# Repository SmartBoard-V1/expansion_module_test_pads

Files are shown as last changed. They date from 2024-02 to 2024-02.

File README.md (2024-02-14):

# # Expansion Module: Test Pads with LEDs








## Overview
This repository is dedicated to the design and implementation of the Test Pads with LEDs Expansion Module, an advanced diagnostic tool crafted to enhance the testing and debugging processes of electronic circuits. With its integration of 8 test pads linked to LED indicators and an additional LED for power status verification, this module stands as a critical asset for developers. It excels in facilitating the examination of signal integrity within FPGA configurations on SmartBoard connectors, especially useful in identifying potential line damage caused by the integration of improperly designed expansion modules. Moreover, its utility extends to the observation and testing of signal outputs from the FPGA to external analysis equipment, such as oscilloscopes or logic analyzers, making it invaluable for real-time signal monitoring during module communication interface testing.

## Key Features
- **LED Indicators**: Features 8 LEDs associated with test pads for immediate visual feedback on signal status, plus one additional LED to confirm power supply integrity.
- **Dual Functionality**:
  - Enables the testing of signal paths on FPGA pads within SmartBoard connectors, aiding in the quick identification of any damaged lines due to faulty expansion module connections.
  - Facilitates the external monitoring and testing of FPGA output signals, allowing for the rerouting of internal signals to this module for analysis with oscilloscopes or logic analyzers.
- **Versatile Testing Capability**: Specially designed for a broad spectrum of electronic testing and debugging scenarios, enhancing both prototype development and troubleshooting efforts.

## Design Documentation

### Schematic Diagram
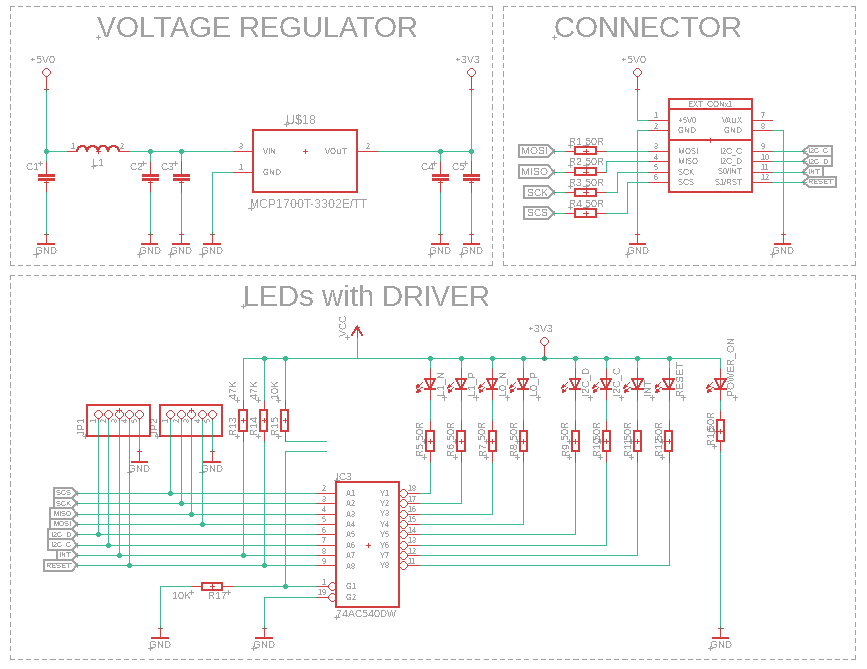
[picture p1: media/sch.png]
Schematic Diagram

*This schematic diagram outlines the layout and connections of the test pads and LEDs, providing a clear guide for replication or modification.*

### Board Design - 2D
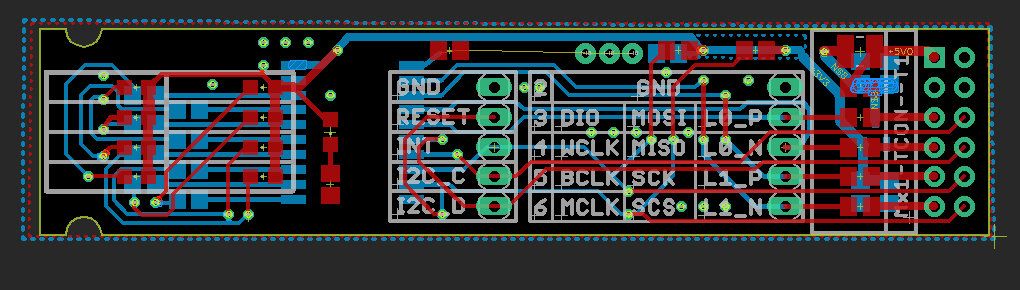
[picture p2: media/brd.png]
Board Design - 2D

*The 2D board design illustrates the placement of LEDs and test pads on the PCB, ensuring optimal accessibility for testing purposes.*

## Contributions and Feedback
We welcome contributions and suggestions for improvements to this module. If you have developed enhancements or have ideas for additional features, please fork the repository, implement your changes, and submit a pull request. For any questions or issues, open an issue in the GitHub repository.

## License
This expansion module is licensed under the MIT License, providing flexibility for both private and commercial use under the following terms:

- **Permission to Use**: Freedom to use, modify, and distribute the module design.
- **Attribution**: While not mandatory, crediting the original author, Adam Łuczak, is appreciated.
- **No Warranty**: Provided "as is", without any warranty; use at your own risk.
- **Liability**: The author bears no liability for any damages or losses.

For full license terms, please refer to the MIT License documentation in this repository.

## Contact
For inquiries or suggestions regarding this project, please contact Adam Łuczak at adam.luczak@outlook.com.

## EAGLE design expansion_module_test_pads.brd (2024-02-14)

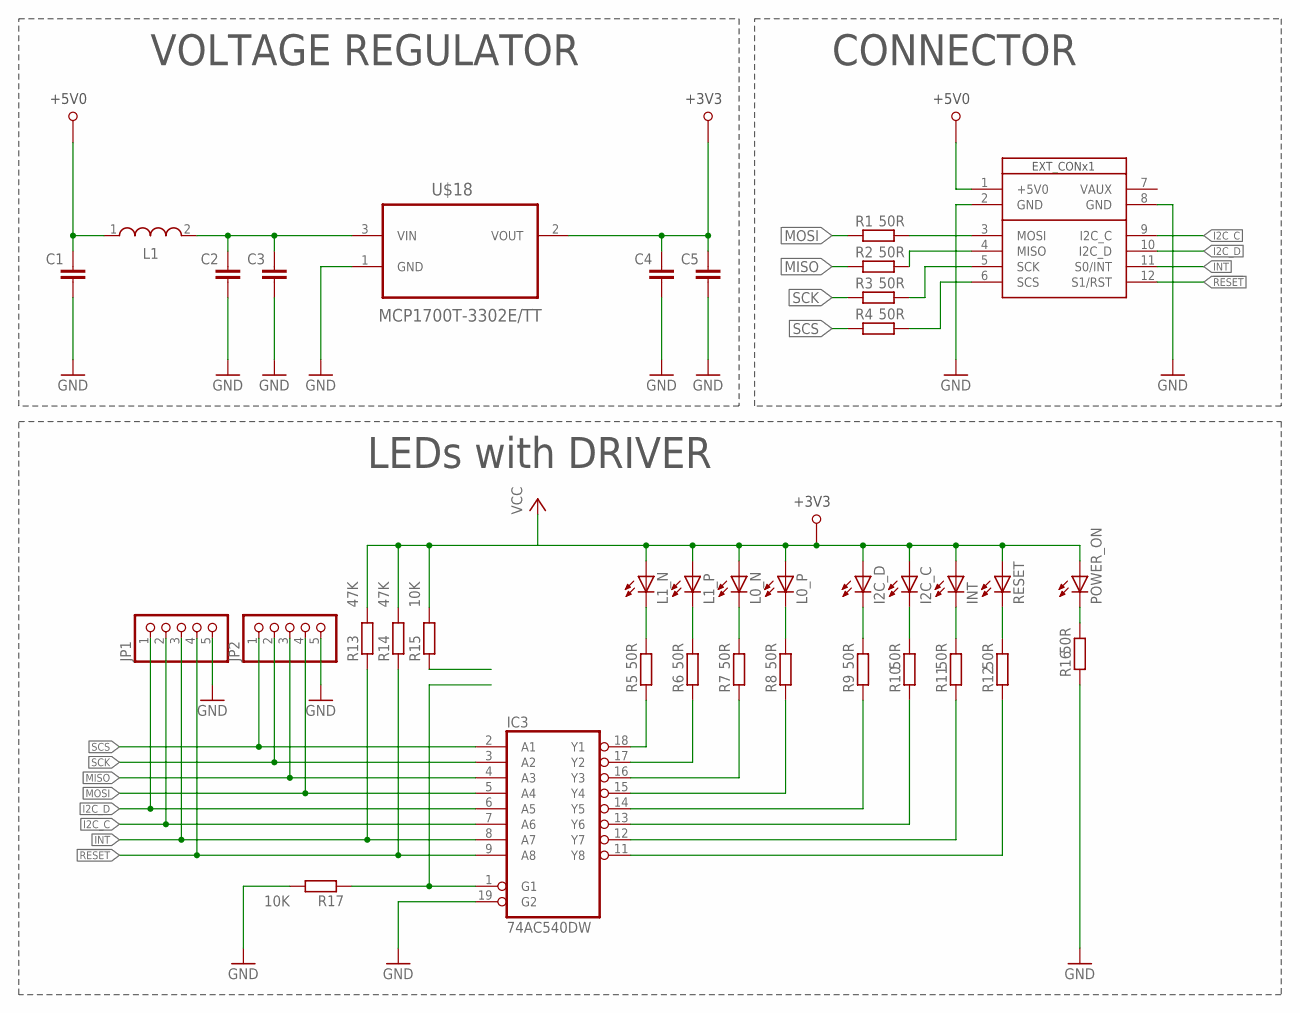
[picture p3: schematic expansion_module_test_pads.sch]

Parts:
C1, C2, C3, C4, C5: C-EUC0805; C0805
I2C_C, I2C_D: LEDCHIPLED_0805; CHIPLED_0805
IC3: 74AC540DW; SO20W
INT: LEDCHIPLED_0805; CHIPLED_0805
JP1, JP2: PINHD-1X5; 1X05
L0_N, L0_P, L1_N, L1_P: LEDCHIPLED_0805; CHIPLED_0805
L1: WE-LQ_1210; WE-LQ_M
POWER_ON: LEDCHIPLED_0805; CHIPLED_0805
R1, R2, R3, R4, R5, R6, R7, R8, R9, R10, R11, R12, R16: 50R; R0805
R13, R14: 47K; R0805
R15, R17: 10K; R0805
RESET: LEDCHIPLED_0805; CHIPLED_0805
U$1: SB_EXT_CON_X1_SPI; SB_EXT_CON_X1_FULL
U$18: MCP1700T-3302E/TT; SOT95P237X112-3N

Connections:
!RESET: IC3.9 (A8), JP1.4, R14.1, U$1.12 (S1/RST)
+3V3: C4.2, C5.2, I2C_C.A, I2C_D.A, INT.A, L0_N.A, L0_P.A, L1_N.A, L1_P.A, POWER_ON.A, R13.2, R14.2, R15.2, RESET.A, U$18.2 (VOUT)
+5V0: C1.2, L1.1, U$1.1 (+5V0)
GND: C1.1, C2.1, C3.1, C4.1, C5.1, IC3.10 (GND), IC3.19 (G2), JP1.5, JP2.5, R16.1, R17.2, U$1.2 (GND), U$1.8 (GND), U$18.1 (GND)
I2C_C: IC3.7 (A6), JP1.2, U$1.9 (I2C_C)
I2C_D: IC3.6 (A5), JP1.1, U$1.10 (I2C_D)
INT: IC3.8 (A7), JP1.3, R13.1, U$1.11 (S0/INT)
MISO: IC3.4 (A3), JP2.3, R2.1
MOSI: IC3.5 (A4), JP2.4, R1.1
unnamed: R1.2, U$1.3 (MOSI)
unnamed: R2.2, U$1.4 (MISO)
unnamed: R3.2, U$1.5 (SCK)
unnamed: R4.2, U$1.6 (SCS)
unnamed: IC3.18 (Y1), R5.1
unnamed: IC3.17 (Y2), R6.1
unnamed: IC3.16 (Y3), R7.1
unnamed: C2.2, C3.2, L1.2, U$18.3 (VIN)
unnamed: IC3.15 (Y4), R8.1
unnamed: IC3.14 (Y5), R9.1
unnamed: IC3.13 (Y6), R10.1
unnamed: IC3.12 (Y7), R11.1
unnamed: IC3.11 (Y8), R12.1
unnamed: L1_N.C, R5.2
unnamed: L1_P.C, R6.2
unnamed: L0_N.C, R7.2
unnamed: L0_P.C, R8.2
unnamed: I2C_D.C, R9.2
unnamed: I2C_C.C, R10.2
unnamed: INT.C, R11.2
unnamed: R12.2, RESET.C
unnamed: POWER_ON.C, R16.2
unnamed: IC3.1 (G1), R17.1
SCK: IC3.3 (A2), JP2.2, R3.1
SCS: IC3.2 (A1), JP2.1, R4.1
VCC: IC3.20 (VCC)

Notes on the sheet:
CONNECTOR
VOLTAGE REGULATOR
LEDs with DRIVER

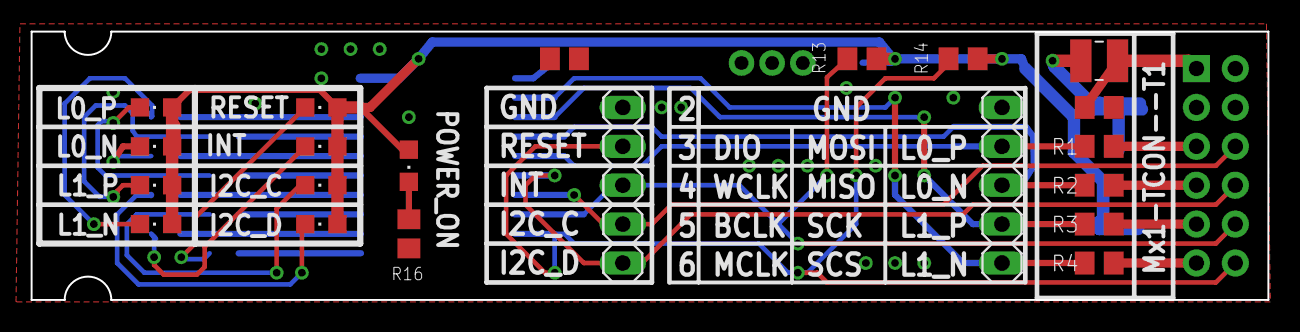
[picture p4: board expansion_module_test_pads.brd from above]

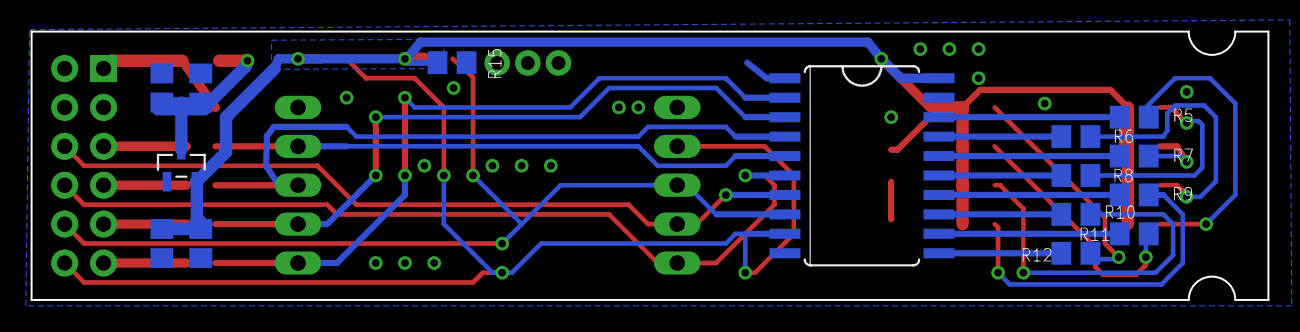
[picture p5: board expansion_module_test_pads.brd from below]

Board: 2 copper layers, 80.8 x 17.5 mm, 37 parts (15 on the bottom side), 34 nets.

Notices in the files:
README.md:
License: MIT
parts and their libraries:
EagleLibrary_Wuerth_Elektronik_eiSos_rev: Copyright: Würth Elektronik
